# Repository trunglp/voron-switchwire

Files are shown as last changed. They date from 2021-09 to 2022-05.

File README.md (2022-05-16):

# voron-switchwire
Setup and config voron switchwire

https://github.com/VoronDesign/Voron-2/tree/Voron2.4/slicer_profiles/PrusaSlicer

https://www.youtube.com/watch?v=dZEL_ycAOLs

https://www.youtube.com/watch?v=T5TGLleu3MA

https://www.reddit.com/r/klippers/comments/kj2h5r/stepbystep_guide_for_ender_3_v2_klipper_w_bltouch/

https://github.com/VoronDesign/Voron-Switchwire/blob/master/Firmware/skr_mini_e3_v2_config.cfg

update klipper 

https://github.com/Klipper3d/klipper/blob/master/docs/FAQ.md#how-do-i-upgrade-to-the-latest-software

https://github.com/narasak/parrot_3d

https://github.com/Annex-Engineering/Annex-Engineering_User_Mods

https://github.com/VoronDesign/VoronUsers/tree/master/printer_mods/Slidr/PanzerChain2.4/stl

https://github.com/Kruze17/HN_Switchwire

https://github.com/boubounokefalos/Ender_SW

https://github.com/henrikssn/VoronUsers/tree/euler/printer_mods/henrikssn/euler_extruder

https://github.com/kanawati975/Voron_Switchwire

https://githubhelp.com/bcdiaconu/klipper_config

https://github.com/AndrewEllis93/Print-Tuning-Guide

https://github.com/Kruze17/HN_Switchwire/tree/main/Slicer%20configs

https://github.com/hymness1/VoronUsers/tree/148301af584e0df7257529359dd0c115a532dded/printer_mods/hymness1/10x11mm_chain_VSW/STLs

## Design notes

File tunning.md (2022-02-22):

### Cân chỉnh Z OFFSET

```wrap
Send: PROBE_CALIBRATE
Recv: // probe at 107.000,85.000 is z=3.100000
Recv: // Starting manual Z probe. Use TESTZ to adjust position.
Recv: // Finish with ACCEPT or ABORT command.
Recv: // Z position: ?????? --> 8.100 <-- ??????
Recv: ok
[...]
Send: TESTZ z=-8
Recv: // Z position: ?????? --> 0.100 <-- 8.100
Recv: ok
[...]
Recv: // Z position: 0.100 --> 0.200 <-- 0.300
Recv: ok
[...]
Send: TESTZ z=-0.1
Recv: // Z position: 0.000 --> 0.100 <-- 0.200
Recv: ok
[...]
Send: TESTZ z=0.1
Recv: // Z position: 0.100 --> 0.200 <-- 0.300
Recv: ok
[...]
Send: TESTZ z=-0.05
Recv: // Z position: 0.100 --> 0.150 <-- 0.200
Recv: ok
[...]
Send: ACCEPT
Recv: // probe: z_offset: 2.950
Recv: // The SAVE_CONFIG command will update the printer config file
Recv: // with the above and restart the printer.
#### Recv: ok
[...]
Send: SAVE_CONFIG
Recv: ok

```

### Kiểm tra đầu dò xem ổn định không 

```wrap
Send: PROBE_ACCURACY
Recv: // PROBE_ACCURACY at X:107.000 Y:115.000 Z:5.025 (samples=10 retract=2.000 speed=30.0 lift_speed=30.0)
Recv: // probe at 107.000,115.000 is z=2.925000
Recv: // probe at 107.000,115.000 is z=2.937500
Recv: // probe at 107.000,115.000 is z=2.937500
Recv: // probe at 107.000,115.000 is z=2.937500
Recv: // probe at 107.000,115.000 is z=2.937500
Recv: // probe at 107.000,115.000 is z=2.925000
Recv: // probe at 107.000,115.000 is z=2.925000
Recv: // probe at 107.000,115.000 is z=2.925000
Recv: // probe at 107.000,115.000 is z=2.925000
Recv: // probe at 107.000,115.000 is z=2.925000
Recv: // probe accuracy results: maximum 2.937500, minimum 2.925000, range 0.012500, average 2.930000, median 2.925000, standard deviation 0.006124
Recv: ok

```

### Kiểm tra từng trigger 

```wrap 

Send: QUERY_ENDSTOPS
Recv: x:open y:open z:open
Recv: ok
[...]
Send: QUERY_ENDSTOPS
Recv: x:open y:open z:TRIGGERED
Recv: ok

```

### PID Tune Heated Bed
Move nozzle to the center of the bed and approximately 5-10mm above the bed surface, then run:

#### PID_CALIBRATE HEATER=heater_bed TARGET=100

It will perform a PID calibration routine that will last about 10 minutes. Once it is finished, 
type SAVE_CONFIG which will save the parameters into your configuration file.

```wrap

Send: PID_CALIBRATE HEATER=heater_bed TARGET=100
Recv: B:43.5 /100.0 T0:55.7 /0.0
Recv: B:43.5 /100.0 T0:55.6 /0.0
Recv: B:43.5 /100.0 T0:55.4 /0.0
Recv: B:43.5 /100.0 T0:55.3 /0.0
Recv: B:43.5 /100.0 T0:55.1 /0.0
Recv: B:43.5 /100.0 T0:55.0 /0.0
Recv: B:43.5 /100.0 T0:55.0 /0.0
Recv: B:43.5 /100.0 T0:54.9 /0.0

```

### PID Tune HEATER Extruder
ok B:33.4 /0.0 T0:32.7 /0.0
#### PID_CALIBRATE HEATER=extruder TARGET=220

```wrap
PID_CALIBRATE HEATER=extruder TARGET=220
B:33.4 /0.0 T0:32.7 /220.0
B:33.4 /0.0 T0:32.7 /220.0
B:33.4 /0.0 T0:32.7 /220.0
B:33.4 /0.0 T0:32.7 /220.0
// PID parameters: pid_Kp=25.197 pid_Ki=1.098 pid_Kd=144.568
// The SAVE_CONFIG command will update the printer config file
// with these parameters and restart the printer.
```

### Pressure_Advance.md

https://github.com/Klipper3d/klipper/blob/master/docs/Pressure_Advance.md

```wrap
SET_VELOCITY_LIMIT SQUARE_CORNER_VELOCITY=1 ACCEL=500
// max_velocity: 300.000000
// max_accel: 500.000000
// max_accel_to_decel: 3250.000000
// square_corner_velocity: 1.000000
ok
TUNING_TOWER COMMAND=SET_PRESSURE_ADVANCE PARAMETER=ADVANCE START=0 FACTOR=.005
// Starting tuning test (start=0.000000 factor=0.005000)
ok
```

https://github.com/AndrewEllis93/Print-Tuning-Guide#tower-method-simple

1) Download and slice the pressure advance tower with your normal print settings (accelerations included).
The only modifications you should make are these:

```wrap 
    120mm/s external perimeter speed
    1 perimeter
    0% infill
    0 top layers
    0 second "minimum layer time" / "layer time goal"
    High fan speed
```

Pressure Advance => Thay đổi sự phân bố của nhựa , không phải thay đổi số lượng nhựa.

Giá trị thấp hơn dẫn đến ít nhựa hơn ở giữa các dòng và nhiều hơn ở các đầu / góc.

Giá trị cao hơn dẫn đến nhiều nhựa hơn ở giữa các dòng và ít hơn ở các đầu / góc.

Hãy nhớ rằng: Hiếm khi có cái gọi Pressure Advance hoàn hảo 

Việc tăng tốc hoặc giảm tốc hầu như luôn luôn không hoàn hảo. Bạn nên luôn luôn sai lầm về phía các giá trị PA thấp hơn.

Pressure Advance  có thể thay đổi với các nhựa  khác nhau. Nên thay đổi nhựa nhớ tính toán lại

Thông thường, tôi chỉ thấy cần thiết phải điều chỉnh theo từng loại nhựa - ABS, PETG, PLA, TPU,

### input shape 

https://www.youtube.com/watch?v=OoWQUcFimX8

https://www.klipper3d.org/RPi_microcontroller.html

https://www.klipper3d.org/Measuring_Resonances.html













```wrap
Setup 

[mcu rpi]
serial: /tmp/klipper_host_mcu

[adxl345]
cs_pin: rpi:None

[resonance_tester]
accel_chip: adxl345
probe_points:
    100,100,20  # an example
#########################

Send: ACCELEROMETER_QUERY
Recv: // adxl345 values (x, y, z): -9408.500010, -1453.345530, -1300.361790
Recv: ok

TEST_RESONANCES AXIS=X

Send: TEST_RESONANCES AXIS=X
Recv: !! Must home axis first: 107.000 100.000 20.000 [0.000]
Recv: ok
Send: M105
Recv: ok B:30.5 /0.0 T0:58.9 /0.0
Send: M105
Recv: ok B:30.5 /0.0 T0:58.2 /0.0
Send: G91
Recv: ok
Send: G28 Z0
Recv: ok
Send: G90
Recv: ok
Send: M105
Recv: ok B:30.5 /0.0 T0:56.5 /0.0
Send: TEST_RESONANCES AXIS=X
Recv: // max_velocity: 200.000000
Recv: // max_accel: 10000.000000
Recv: // max_accel_to_decel: 10000.000000
Recv: // square_corner_velocity: 4.000000
Recv: // Testing frequency 5 Hz
Recv: // Testing frequency 6 Hz
......

Recv: // Testing frequency 109 Hz
Recv: // Testing frequency 110 Hz
Recv: // Testing frequency 111 Hz
Recv: // Testing frequency 112 Hz
Recv: // Testing frequency 133 Hz
Recv: // max_velocity: 200.000000
Recv: // max_accel: 1000.000000
Recv: // max_accel_to_decel: 500.000000
Recv: // square_corner_velocity: 4.000000
Recv: // xy-axis accelerometer stats: drops=0,overflows=3,time_per_sample=0.000314001,start_range=0.000068,end_range=0.000037
Recv: // Wait for calculations..
Recv: // Resonances data written to /tmp/resonances_x_20211009_032546.csv file
Recv: ok
```    

~/klipper/scripts/calibrate_shaper.py /tmp/resonances_x_*.csv -o /tmp/shaper_calibrate_x.png

~/klipper/scripts/calibrate_shaper.py /tmp/resonances_y_*.csv -o /tmp/shaper_calibrate_y.png

```wrap
pi@octopi:/tmp $ rm resonances_x_20211009_032546.csv
pi@octopi:/tmp $ ~/klipper/scripts/calibrate_shaper.py /tmp/resonances_x_*.csv -o /tmp/shaper_calibrate_x.png
Fitted shaper 'zv' frequency = 34.6 Hz (vibrations = 27.4%, smoothing ~= 0.130)
To avoid too much smoothing with 'zv', suggested max_accel <= 4500 mm/sec^2
Fitted shaper 'mzv' frequency = 26.2 Hz (vibrations = 7.6%, smoothing ~= 0.297)
To avoid too much smoothing with 'mzv', suggested max_accel <= 2000 mm/sec^2
Fitted shaper 'ei' frequency = 32.8 Hz (vibrations = 7.4%, smoothing ~= 0.299)
To avoid too much smoothing with 'ei', suggested max_accel <= 2000 mm/sec^2
Fitted shaper '2hump_ei' frequency = 39.0 Hz (vibrations = 5.4%, smoothing ~= 0.355)
To avoid too much smoothing with '2hump_ei', suggested max_accel <= 1500 mm/sec^2
Fitted shaper '3hump_ei' frequency = 48.0 Hz (vibrations = 5.3%, smoothing ~= 0.356)
To avoid too much smoothing with '3hump_ei', suggested max_accel <= 1500 mm/sec^2
Recommended shaper is mzv @ 26.2 Hz
```   





```wrap
[input_shaper]
shaper_freq_x: 27
shaper_freq_y: 36
shaper_type: mzv
```

### Selecting max_accel

https://www.klipper3d.org/Resonance_Compensation.html

https://www.klipper3d.org/prints/ringing_tower.stl

```wrap
SET_PRESSURE_ADVANCE ADVANCE=0
// pressure_advance: 0.000000
// pressure_advance_smooth_time: 0.040000
ok
TUNING_TOWER COMMAND=SET_VELOCITY_LIMIT PARAMETER=ACCEL START=1250 FACTOR=100 BAND=5
// Ending tuning test mode
// Starting tuning test (start=1250.000000 factor=100.000000)
ok
TUNING_TOWER COMMAND=SET_VELOCITY_LIMIT PARAMETER=ACCEL START=1250 FACTOR=100 BAND=5
// Ending tuning test mode
// Starting tuning test (start=1250.000000 factor=100.000000)
```

# Verify stepper_buzz
```wrap
STEPPER_BUZZ STEPPER=stepper_z
STEPPER_BUZZ STEPPER=stepper_z1
STEPPER_BUZZ STEPPER=stepper_z2
```

https://www.reddit.com/r/klippers/comments/gxnxij/trying_different_retract_settings_with_tuning/

# Tuning retract
```wrap
[firmware_retraction]
retract_length: 0.8
#   The length of filament (in mm) to retract when G10 is activated, and to
#   unretract when G11 is activated (but see unretract_extra_length below).
#   The default is 0 mm.
retract_speed: 40
#   The length (in mm) of *additional* filament to add when unretracting.
unretract_extra_length: 0
#   The speed of retraction, in mm/s. The default is 20 mm/s.
unretract_speed: 40
######################
[gcode_macro SET_RETRACTIONLENGTH]
gcode:
  SET_RETRACTION RETRACT_LENGTH={params.LENGTH|float}
  GET_RETRACTION
```

```wrap
TUNING_TOWER COMMAND=SET_RETRACTIONLENGTH PARAMETER=LENGTH START=0.5 FACTOR=.007
```

```wrap
setup slicer:
set 0 retraction length (PrusaSlicer/SuperSlicer: Printer Settings -> Extruder 1 -> Retraction -> Length)
disable wipe (PrusaSlicer/SuperSlicer: Printer Settings -> Extruder 1 -> Retraction -> Wipe while retracting)
enable use firmware retractions (PrusaSlicer/SuperSlicer: Printer Settings -> General -> Advanced -> Use firmware retractions)
```

### Extrusion multiplier và Pressure Advance Có quan hệ với nhau, nên chỉnh 1 trong 2 giá trị không đúng dẫn đến in không đẹp 

Approximate Values
|Hotend  |	Flow Rate (mm3/sec) |
| --- | --- |
|E3D V6  |	11
|E3D Revo |	15
|Dragon SF|	15
|Dragon HF |	24
|Mosquito |	20
|Mosquito Magnum |	30

## cHow Volumetric Flow Rate Relates to Print Speed

Working out how quickly you can print at a given volumetric flow rate is quite simple:

   ### speed = volumetric flow / layer height / line width
    
  ####  167  = 15 / 0.2 / 0.45 
    
  ####  222  = 20 / 0.2 / 0.45 
    
Or, inversely,

 ### volumetric flow = speed * line width * layer height

For example, if your hotend is capable of 24mm3/sec, and you are printing with 0.4mm line width, at 0.2mm layer height:

    24 / 0.4 / 0.2 = Maximum print speed of 300mm/sec

```wrap
# Home, get position, throw around toolhead, home again.
# If MCU stepper positions (first line in GET_POSITION) are greater than a full step different (your number of microsteps), then skipping occured.
# We only measure to a full step to accomodate for endstop variance.
# Example: TEST_SPEED SPEED=300 ACCEL=5000 ITERATIONS=10
[gcode_macro TEST_SPEED]
gcode:
	# Speed
	{% set speed  = params.SPEED|default(printer.configfile.settings.printer.max_velocity)|int %}
	# Iterations
	{% set iterations = params.ITERATIONS|default(5)|int %}
	# Acceleration
	{% set accel  = params.ACCEL|default(printer.configfile.settings.printer.max_accel)|int %}
	# Bounding box (in case the machine min/maxes are not perfect)
	{% set bound = params.BOUND|default(20)|int %}
	
	# Set speed test bounds (machine minimum/maximum positions, inset by the bounding box)
	{% set x_min = printer.toolhead.axis_minimum.x + bound %}
	{% set x_max = printer.toolhead.axis_maximum.x - bound %}
	{% set y_min = printer.toolhead.axis_minimum.y + bound %}
	{% set y_max = printer.toolhead.axis_maximum.y - bound %}

	# Save current gcode state (absolute/relative, etc)
	SAVE_GCODE_STATE NAME=TEST_SPEED
	
	{ action_respond_info("TEST_SPEED: starting %d iterations at speed %d, accel %d" % (iterations, speed, accel)) }

	# Absolute positioning
	G90
	
	# Set new limits
	SET_VELOCITY_LIMIT VELOCITY={speed} ACCEL={accel} ACCEL_TO_DECEL={accel / 2}

	# Home and get position for comparison later:
		G28
		# QGL if not already QGLd (only if QGL section exists in config)
		{% if printer.configfile.settings.quad_gantry_level %}
			{% if printer.quad_gantry_level.applied == False %}
				QUAD_GANTRY_LEVEL
				G28 Z
			{% endif %}
		{% endif %}	
		G0 X{printer.toolhead.axis_maximum.x} Y{printer.toolhead.axis_maximum.y} F{30 * 60}
		G4 P1000 
		GET_POSITION

	# Go to starting position
	G0 X{x_min} Y{y_min} Z{bound + 10} F{speed * 60}

	{% for i in range(iterations) %}
		# Diagonals
		G0 X{x_min} Y{y_min} F{speed * 60}
		G0 X{x_max} Y{y_max} F{speed * 60}
		G0 X{x_min} Y{y_min} F{speed * 60}
		G0 X{x_max} Y{y_min} F{speed * 60}
		G0 X{x_min} Y{y_max} F{speed * 60}
		G0 X{x_max} Y{y_min} F{speed * 60}
		
		# Box
		G0 X{x_min} Y{y_min} F{speed * 60}
		G0 X{x_min} Y{y_max} F{speed * 60}
		G0 X{x_max} Y{y_max} F{speed * 60}
		G0 X{x_max} Y{y_min} F{speed * 60}
	{% endfor %}

	# Restore max speed/accel/accel_to_decel to their configured values
	SET_VELOCITY_LIMIT VELOCITY={printer.configfile.settings.printer.max_velocity} ACCEL={printer.configfile.settings.printer.max_accel} ACCEL_TO_DECEL={printer.configfile.settings.printer.max_accel_to_decel} 

	# Re-home XY and get position again for comparison:
		G28 X Y
		# Go to XY home positions (in case your homing override leaves it elsewhere)
		G0 X{printer.toolhead.axis_maximum.x} Y{printer.toolhead.axis_maximum.y} F{30 * 60}
		G4 P1000 
		GET_POSITION

	# Restore previous gcode state (absolute/relative, etc)
	RESTORE_GCODE_STATE NAME=TEST_SPEED
    
```

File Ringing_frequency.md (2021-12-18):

Setup slicer 









Increase max_accel and max_accel_to_decel parameters in your printer.cfg to 7000. Note that this is only needed for tuning, and more proper value will be selected in the corresponding section.
If square_corner_velocity parameter was changed, revert it back to 5.0. It is not advised to increase it when using the input shaper because it can cause more smoothing in parts - it is better to use higher acceleration value instead.
Restart the firmware: RESTART.
Disable Pressure Advance: SET_PRESSURE_ADVANCE ADVANCE=0.
If you have already added [input_shaper] section to the printer.cfg, execute SET_INPUT_SHAPER SHAPER_FREQ_X=0 SHAPER_FREQ_Y=0 command. If you get "Unknown command" error, you can safely ignore it at this point and continue with the measurements.
Execute the command TUNING_TOWER COMMAND=SET_VELOCITY_LIMIT PARAMETER=ACCEL START=1250 FACTOR=100 BAND=5. Basically, we try to make ringing more pronounced by setting different large values for acceleration. This command will increase the acceleration every 5 mm starting from 1500 mm/sec^2: 1500 mm/sec^2, 2000 mm/sec^2, 2500 mm/sec^2 and so forth up until 7000 mm/sec^2 at the last band.
Print the test model sliced with the suggested parameters.
You can stop the print earlier if the ringing is clearly visible and you see that acceleration gets too high for your printer (e.g. printer shakes too much or starts skipping steps).

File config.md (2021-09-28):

# voron-switchwire

### Setup and config voron switchwire on SKR Mini E3 V1.2

MainsailOS or FluiddPi or Octoprint



### Step 1: 

git clone https://github.com/Klipper3d/klipper

./klipper/scripts/install-octopi.sh

### Step 2:

cd ~/klipper/

make menuconfig



Chú ý: 

SKR mini E3 V1.2 => pin !PC13
SKR mini E3 V2.0 => pin !PC14

### Step 3: build firmware

```wrap

pi@octopi:~/klipper $ make clean
pi@octopi:~/klipper $ make
  Creating symbolic link out/board
  Building out/autoconf.h
  Compiling out/src/sched.o
  Compiling out/src/command.o
  Compiling out/src/basecmd.o
  Compiling out/src/debugcmds.o
  Compiling out/src/initial_pins.o
  Compiling out/src/gpiocmds.o
  Compiling out/src/stepper.o
  Compiling out/src/endstop.o
  Compiling out/src/trsync.o
  Compiling out/src/adccmds.o
  Compiling out/src/spicmds.o
  Compiling out/src/thermocouple.o
  Compiling out/src/i2ccmds.o
  Compiling out/src/pwmcmds.o
  Compiling out/src/spi_software.o
  Compiling out/src/sensor_adxl345.o
  Compiling out/src/lcd_st7920.o
  Compiling out/src/lcd_hd44780.o
  Compiling out/src/buttons.o
  Compiling out/src/tmcuart.o
  Compiling out/src/neopixel.o
  Compiling out/src/pulse_counter.o
  Compiling out/src/stm32/watchdog.o
  Compiling out/src/stm32/gpio.o
  Compiling out/src/generic/crc16_ccitt.o
  Compiling out/src/generic/armcm_boot.o
  Compiling out/src/generic/armcm_irq.o
  Compiling out/src/generic/armcm_reset.o
  Compiling out/src/../lib/stm32f1/system_stm32f1xx.o
  Compiling out/src/stm32/stm32f1.o
  Compiling out/src/generic/armcm_timer.o
  Compiling out/src/stm32/adc.o
  Compiling out/src/stm32/i2c.o
  Compiling out/src/stm32/spi.o
  Compiling out/src/stm32/usbfs.o
  Compiling out/src/stm32/chipid.o
  Compiling out/src/generic/usb_cdc.o
  Compiling out/src/stm32/hard_pwm.o
  Building out/compile_time_request.o
Version: v0.9.1-659-g69d9497d
  Preprocessing out/src/generic/armcm_link.ld
  Linking out/klipper.elf
  Creating hex file out/klipper.bin
pi@octopi:~/klipper $

```

### Check my config

```wrap

pi@octopi:~/klipper $ cat .config
CONFIG_LOW_LEVEL_OPTIONS=y
# CONFIG_MACH_AVR is not set
# CONFIG_MACH_ATSAM is not set
# CONFIG_MACH_ATSAMD is not set
# CONFIG_MACH_LPC176X is not set
CONFIG_MACH_STM32=y
# CONFIG_MACH_RP2040 is not set
# CONFIG_MACH_PRU is not set
# CONFIG_MACH_LINUX is not set
# CONFIG_MACH_SIMU is not set
CONFIG_STEP_DELAY=2
CONFIG_BOARD_DIRECTORY="stm32"
CONFIG_MCU="stm32f103xe"
CONFIG_CLOCK_FREQ=72000000
CONFIG_USBSERIAL=y
CONFIG_FLASH_START=0x8007000
CONFIG_FLASH_SIZE=0x10000
CONFIG_RAM_START=0x20000000
CONFIG_RAM_SIZE=0x5000
CONFIG_STACK_SIZE=512
CONFIG_STM32_SELECT=y
CONFIG_MACH_STM32F103=y
# CONFIG_MACH_STM32F207 is not set
# CONFIG_MACH_STM32F401 is not set
# CONFIG_MACH_STM32F405 is not set
# CONFIG_MACH_STM32F407 is not set
# CONFIG_MACH_STM32F429 is not set
# CONFIG_MACH_STM32F446 is not set
# CONFIG_MACH_STM32F031 is not set
# CONFIG_MACH_STM32F042 is not set
# CONFIG_MACH_STM32F070 is not set
# CONFIG_MACH_STM32F072 is not set
CONFIG_MACH_STM32F1=y
CONFIG_HAVE_STM32_USBFS=y
CONFIG_HAVE_STM32_CANBUS=y
# CONFIG_STM32_FLASH_START_2000 is not set
# CONFIG_STM32_FLASH_START_5000 is not set
CONFIG_STM32_FLASH_START_7000=y
# CONFIG_STM32_FLASH_START_8800 is not set
# CONFIG_STM32_FLASH_START_10000 is not set
# CONFIG_STM32_FLASH_START_800 is not set
# CONFIG_STM32_FLASH_START_4000 is not set
# CONFIG_STM32_FLASH_START_0000 is not set
CONFIG_STM32_CLOCK_REF_8M=y
# CONFIG_STM32_CLOCK_REF_12M is not set
# CONFIG_STM32_CLOCK_REF_16M is not set
# CONFIG_STM32_CLOCK_REF_25M is not set
# CONFIG_STM32_CLOCK_REF_INTERNAL is not set
CONFIG_CLOCK_REF_FREQ=8000000
CONFIG_STM32F0_TRIM=16
CONFIG_STM32_USB_PA11_PA12=y
# CONFIG_STM32_SERIAL_USART1 is not set
# CONFIG_STM32_SERIAL_USART1_ALT_PB7_PB6 is not set
# CONFIG_STM32_SERIAL_USART2 is not set
# CONFIG_STM32_SERIAL_USART2_ALT_PD6_PD5 is not set
# CONFIG_STM32_SERIAL_USART3 is not set
# CONFIG_STM32_SERIAL_USART3_ALT_PD9_PD8 is not set
# CONFIG_STM32_CANBUS_PA11_PA12 is not set
# CONFIG_STM32_CANBUS_PB8_PB9 is not set
CONFIG_CANBUS_FREQUENCY=500000
CONFIG_USB_VENDOR_ID=0x1d50
CONFIG_USB_DEVICE_ID=0x614e
CONFIG_USB_SERIAL_NUMBER_CHIPID=y
CONFIG_USB_SERIAL_NUMBER="12345"

#
# USB ids
#
# end of USB ids

# CONFIG_CUSTOM_STEP_DELAY is not set
CONFIG_INITIAL_PINS="!PC13"
CONFIG_HAVE_GPIO=y
CONFIG_HAVE_GPIO_ADC=y
CONFIG_HAVE_GPIO_SPI=y
CONFIG_HAVE_GPIO_I2C=y
CONFIG_HAVE_GPIO_HARD_PWM=y
CONFIG_HAVE_GPIO_BITBANGING=y
CONFIG_HAVE_STRICT_TIMING=y
CONFIG_HAVE_CHIPID=y
CONFIG_INLINE_STEPPER_HACK=y

```

### Step 4: Copy klipper.bin  to sd card and rename to FIRMWARE.BIN => flash firmware board SKR mini E3 V1.2

```wrap

pi@octopi:~/klipper $ pwd
/home/pi/klipper
pi@octopi:~/klipper $ ls out/
autoconf.h     board-link              compile_time_request.o    klipper.dict  src
board          compile_time_request.c  compile_time_request.txt  klipper.elf
board-generic  compile_time_request.d  klipper.bin               lib
pi@octopi:~/klipper $

```

### Step 5:



### Step 6:





### Step 7:



### Tham Khảo





https://www.youtube.com/watch?v=c7cVv9qbSMw

################################

https://www.youtube.com/watch?v=T5TGLleu3MA

https://docs.vorondesign.com/build/software/miniE3_v12_klipper.html

https://www.reddit.com/r/ender3/comments/dtl8re/skr_mini_e3_12_klipper_configguide_including/

https://github.com/Klipper3d/klipper/blob/master/config/generic-bigtreetech-skr-mini-e3-v1.2.cfg

https://github.com/Klipper3d/klipper/tree/master/config

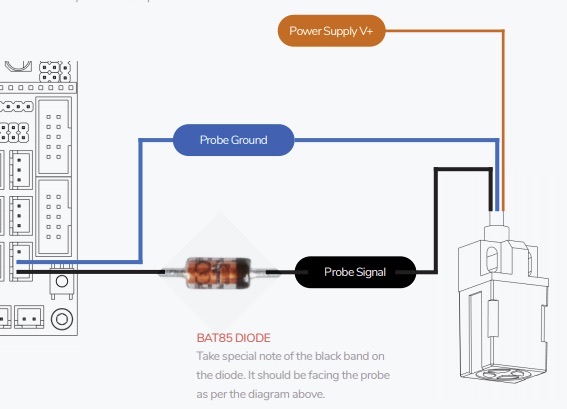
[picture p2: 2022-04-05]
6FBBFF84-A0F4-4B92-9275-398039277366.jpeg

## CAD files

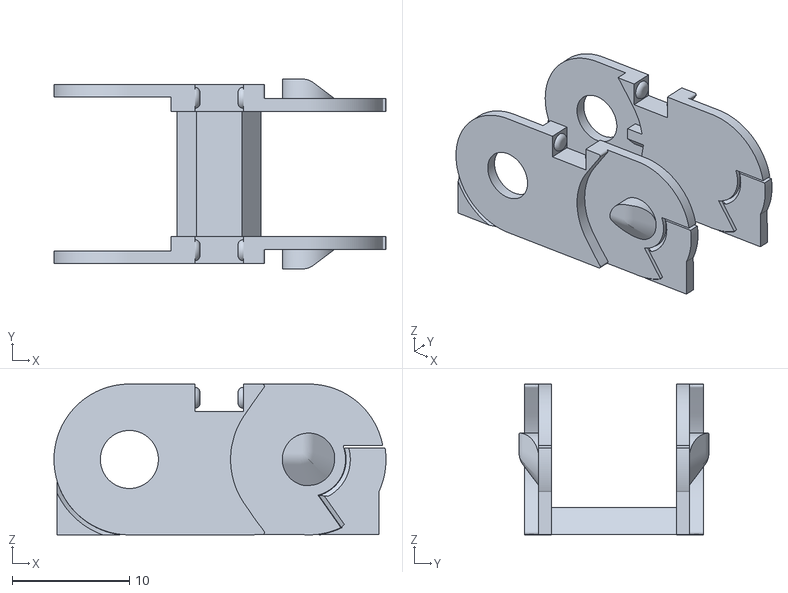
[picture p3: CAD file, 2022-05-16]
STL/chainlink_fix.stl
28.3 x 16.2 x 12.9

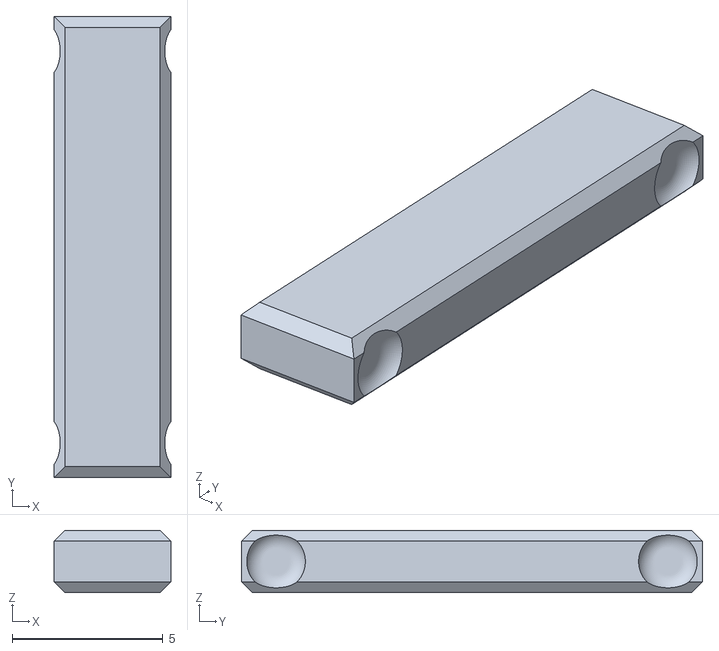
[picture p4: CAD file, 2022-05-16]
STL/clip_fix.stl
3.87 x 15.3 x 2.07

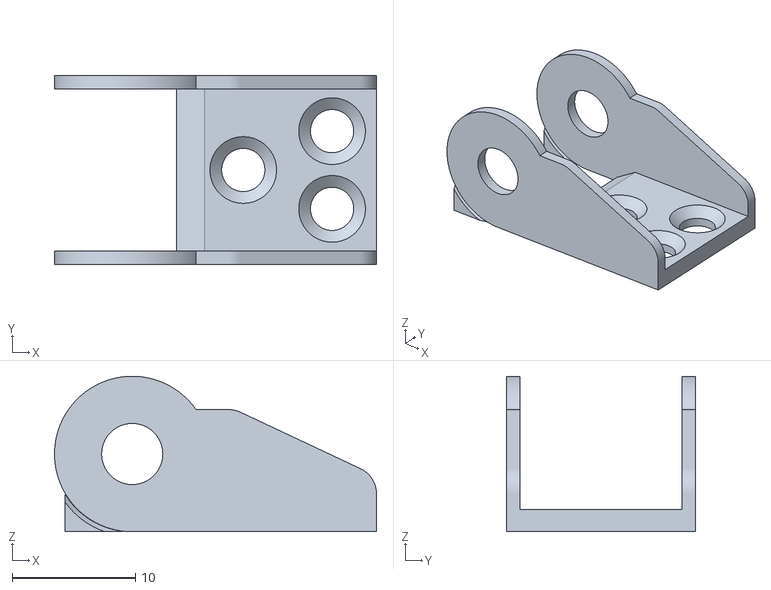
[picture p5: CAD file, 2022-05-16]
STL/unfixed_end_PT90_fix.stl
26.1 x 15.3 x 12.6

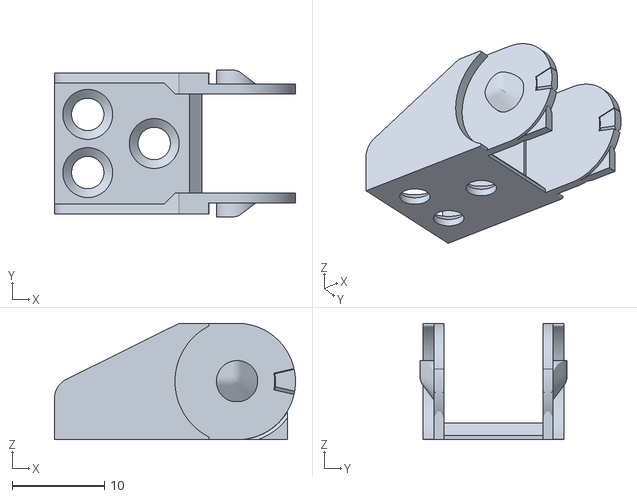
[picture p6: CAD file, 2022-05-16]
STL/fixed_end_90PT_fix.stl
26.1 x 15.9 x 12.6

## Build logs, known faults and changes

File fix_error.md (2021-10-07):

Nếu gặp lỗi "min_temp or max_temp" => nguyên nhân dây Sensor bị đứt hoặc không gắn dây sensor

```wrap 

Recv: // MCU 'mcu' shutdown: ADC out of range
Recv: // This generally occurs when a heater temperature exceeds
Recv: // its configured min_temp or max_temp.
Recv: // Once the underlying issue is corrected, use the
Recv: // "FIRMWARE_RESTART" command to reset the firmware, reload the
Recv: // config, and restart the host software.
Recv: // Printer is shutdown
Recv: // Klipper state: Not ready
Recv: !! MCU 'mcu' shutdown: ADC out of range

```

Không thể move các axis X Y Z khi chưa homing

If the motors are disabled (via an M84 or M18 command) then the motors will need to be homed again prior to movement.

#### Lỗi Move exceeds maximum extrusion (0.752mm^2 vs 0.640mm^2)
Your printer's firmware reported an error. Due to that the ongoing print job will be cancelled. Reported error: Move exceeds maximum extrusion (0.752mm^2 vs 0.640mm^2)
=> put M82 at the end of START_PRINT to revert the effect of M83
M83 or G92 E0 causing "move exceeds max extrusion"

#### Lỗi  pid_calibrate interrupted

```wrap
Recv: // Klipper state: Shutdown
Recv: !! pid_calibrate interrupted

Fix: 

[verify_heater bed]  
heating_gain: 2 
check_gain_time:35  
hysteresis: 10  
max_error: 130 
```

#### LỖI KHÔNG KẾT NỐI VỚI MCU

Nguyên nhân lỗi này là do Cáp kết nối , file config MCU, Thẻ nhớ SD card cần format lại đúng chuẩn

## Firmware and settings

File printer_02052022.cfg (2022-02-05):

##klipper SKR Mini E3 V1.2 edit by lptrung
############################# ##########
##
#[mcu rpi]
#serial: /tmp/klipper_host_mcu

#[adxl345]
#cs_pin: rpi:None

#[resonance_tester]
##accel_chip: adxl345
#probe_points:
#    107,100,20  # an example    
######################################


[printer]
kinematics: corexz
##############################
#max_velocity: 200
#max_accel: 1000
#max_z_velocity: 50
#max_z_accel: 1000
#square_corner_velocity: 4.0
##################################

#kinematics: corexz
#max_velocity: 200
#max_accel: 1000
#max_z_velocity: 50
#max_z_accel: 1000
#square_corner_velocity: 4.0

max_velocity: 250
max_accel: 2200
max_accel_to_decel: 1500
max_z_velocity: 24
max_z_accel: 400
square_corner_velocity: 4.0



[force_move]
enable_force_move: true

### Test XYZ
#max_velocity: 500
#max_accel: 7000
#max_accel_to_decel: 7000
#max_z_velocity: 100
#max_z_accel: 1000
#square_corner_velocity: 5

#max_velocity: 300
#max_accel: 3250
#max_accel_to_decel: 3250
#max_z_velocity: 100
#max_z_accel: 1000
#square_corner_velocity: 5.0


[input_shaper]
#shaper_type: mzv
#shaper_freq_x: 26   ## 100 x 6 / 16 =37.5
#shaper_freq_y: 33.8  ### 600 /14 = 42.8

shaper_type_x: ei
#shaper_freq_x: 0
shaper_freq_x: 38.0 ## accel <=1900
shaper_type_y: mzv   ## accel <=3800
shaper_freq_y: 33.8
#shaper_freq_y: 0
#shaper_type_y: ei   ## accel <=3800
#shaper_freq_y: 42.8

[probe]
##pin: !PA1
pin: ^!PC14

#khoang cach tu mui in toi dau do ( Probe) 
x_offset: 0.0
y_offset: 25.0
##For moquito 
#z_offset = 1.930
## MK8
#z_offset: 1.9
speed: 50
##speed: 100 ##tesst
#samples: 3
#samples_result: median
sample_retract_dist: 5
#lift_speed: 50

#samples: 3
#samples_result: average

#sample_retract_dist: 1
#lift_speed: 50

[stepper_x]
step_pin: PB13
dir_pin: PB12
enable_pin: !PB14
microsteps: 16
rotation_distance: 39.7
endstop_pin: ^PC0
position_endstop: 215
position_max: 215
homing_speed: 50

[tmc2209 stepper_x]
uart_pin: PB15
run_current: 0.45
hold_current: 0.3
stealthchop_threshold: 250


[stepper_y]
step_pin: PB10
dir_pin: !PB2
enable_pin: !PB11
microsteps: 16
rotation_distance: 39.8
endstop_pin: ^PC1
position_endstop: 210
position_max: 210
homing_speed: 50

[tmc2209 stepper_y]
uart_pin: PC6
run_current: 0.5
hold_current: 0.3
stealthchop_threshold: 250

[stepper_z]
step_pin: PB0
dir_pin: PC5
enable_pin: !PB1
microsteps: 16
rotation_distance: 39.7
endstop_pin: probe:z_virtual_endstop
position_max: 220
position_min: -2
homing_speed: 40

[tmc2209 stepper_z]
uart_pin: PC10
run_current: 0.45
hold_current: 0.3
stealthchop_threshold: 250


[extruder]
step_pin: PB3
dir_pin: PB4
enable_pin: !PD2
microsteps: 16
rotation_distance: 4.44
nozzle_diameter: 0.400
filament_diameter: 1.750
heater_pin: PC8
min_temp: 0
max_temp: 260
min_extrude_temp: 50
sensor_pin: PA0
max_extrude_only_distance: 100.0
##lptrung edit
#pressure_advance: 0.044  ###gia tri 8.4
##pressure_advance:0.045 ### KQ= 9*0.005 = 0.045
pressure_advance:0.04  ### KQ= 30*0.005 = 0.015
pressure_advance_smooth_time: 0.040
## nhua can nong chay, gia tri la 0.03 se khong bi dut doan
###m ender 3 pro  ####  MK8 OK
#sensor_type: EPCOS 100K B57560G104F   
#control = pid
##pid_Kp=33.750
#pid_Ki=2.009
#pid_Kd=141.749

###m Mosquito  #### 
#sensor_type: EPCOS 100K B57560G104F   
#control = pid
#pid_Kp=33.796
#pid_Ki=1.976
#pid_Kd=144.479


###m Mosquito ok  #### 
sensor_type: NTC 100K MGB18-104F39050L32
control: pid
pid_Kp=32.815
pid_Ki=1.971
pid_Kd=136.591


#[thermistor mosquito_thermistor]
#temperature1 = 20
#resistance1 = 613400
#temperature2 = 190
#resistance2 = 4509
#temperature3 = 260
#resistance3 = 1359

[tmc2209 extruder]
uart_pin: PC11
run_current: 0.25
hold_current: 0.2
stealthchop_threshold: 250

### Z homing
[homing_override]
axes: z
set_position_z: 0
gcode:
    G90
    BED_MESH_CLEAR
    STATUS_HOMING
    G0 Z5 F500
    G28 X0 Y0
    G0 X107 Y85 F9000
    ##G0 X5 Y5 F2000
    G28 Z0 F200
    G0 Z5 F500

[bed_mesh]
speed: 100
#speed: 130  ## tesst
horizontal_move_z: 5
mesh_min: 25,25
mesh_max: 190,195
probe_count: 5,5
fade_end: 10
split_delta_z: .01
move_check_distance: 3
algorithm: lagrange
mesh_pps : 2,2
relative_reference_index: 12

#mesh_pps : 5,5
#bicubic_tension: 0.8
#split_delta_z: 0.025
#fade_end: 10  ### gia tri 2 ban khong phang
#split_delta_z: 0.01
#move_check_distance: 3
#mesh_pps : 2,2
#algorithm: lagrange  ##lagrange
#relative_reference_index: 12



[heater_bed]
heater_pin: PC9
sensor_type: EPCOS 100K B57560G104F
#lptrung sensor_type: ATC Semitec 104GT-2
sensor_pin: PC3
control = pid
pid_kp = 70.844
pid_ki = 1.414
pid_kd = 887.318
min_temp: 0
max_temp: 110
###// PID parameters: pid_Kp=70.844 pid_Ki=1.414 pid_Kd=887.318
[fan]
pin: PA8

# thermally controlled hotend fan
#lptrung  [heater_fan my_nozzle_fan]
#lptrung  pin: PC7
#lptrung  max_power: 1.0
kick_start_time: 0.100
#lptrung  heater: extruder
#lptrung  heater_temp: 50.0
#lptrung  fan_speed: 1.0




[mcu]
serial: /dev/serial/by-id/usb-Klipper_stm32f103xe_34FFD7055055323921710143-if00


[static_digital_output usb_pullup_enable]
pins: !PC13

[board_pins]
aliases:
    # EXP1 header
    EXP1_1=PB5, EXP1_3=PA9,   EXP1_5=PA10, EXP1_7=PB8, EXP1_9=<GND>,
    EXP1_2=PB6, EXP1_4=<RST>, EXP1_6=PB9,  EXP1_8=PB7, EXP1_10=<5V>

# See the sample-lcd.cfg file for definitions of common LCD displays.

######################################################################
# 128x64 Full Graphic Creality CR10 / ENDER 3 stockdisplay
######################################################################

# This section is used for a Creality "12864" display with a single
# ribbon cable between the display's EXP3 plug and the
# micro-controller board's EXP1 connector.

[display]
lcd_type: st7920
cs_pin: EXP1_7
sclk_pin: EXP1_6
sid_pin: EXP1_8
encoder_pins: ^EXP1_5, ^EXP1_3
click_pin: ^!EXP1_2

[output_pin beeper]
pin: EXP1_1

[virtual_sdcard]
path: /home/pi/sdcard

################
[gcode_macro G29]
gcode:
    BED_MESH_CLEAR
    BED_MESH_CALIBRATE
    BED_MESH_PROFILE SAVE=default
    BED_MESH_PROFILE LOAD=default
    
###############LED################
[neopixel sb_leds]
pin: PA1
chain_count: 3
color_order: GRBW
initial_RED: 0.0
initial_GREEN: 0.0
initial_BLUE: 0.0
initial_WHITE: 0.0

[gcode_macro status_off]
gcode:
    set_logo_leds_off transmit=0
    set_nozzle_leds_off
	
# #   Sets the initial LED color of the Neopixel. Each value should be
# #   between 0.0 and 1.0. The WHITE option is only available on RGBW
# #   LEDs. The default for each color is 0.#
#
# Most configuration for the macros can be done by modifying the variables in the _sb_vars macro
# at the start of this file. 
#
# MACROS
#
# The following status macros are available:
#    STATUS_READY
#    STATUS_OFF
#    STATUS_BUSY
#    STATUS_HEATING
#    STATUS_LEVELING
#    STATUS_HOMING
#    STATUS_CLEANING
#    STATUS_MESHING
#    STATUS_CALIBRATING_Z
# With additional macros for direct control:
#    SET_NOZZLE_LEDS_ON
#    SET_LOGO_LEDS_OFF
#    SET_NOZZLE_LEDS_OFF
#
# Contributed by Voron discord users wile.e, Tetsunosuke, and etherwalker

[gcode_macro _sb_vars]
# User settings for the StealthBurner status leds. You can change the status colors and led
# configurations for the logo and nozzle here.
variable_colors: {
        'logo': { # Colors for logo states
            'busy': {'r': 0.4, 'g': 0.0, 'b': 0.0, 'w': 0.0},
            'cleaning': {'r': 0.0, 'g': 0.02, 'b': 0.5, 'w': 0.0},
            'calibrating_z': {'r': 0.8, 'g': 0., 'b': 0.35, 'w': 0.0},
            'heating': {'r': 0.3, 'g': 0.18, 'b': 0.0, 'w': 0.0},
            'homing': {'r': 0.0, 'g': 0.6, 'b': 0.2, 'w': 0.0},
            'leveling': {'r': 0.5, 'g': 0.1, 'b': 0.4, 'w': 0.0},
            'meshing': {'r': 0.2, 'g': 1.0, 'b': 0.0, 'w': 0.0},
            'off': {'r': 0.0, 'g': 0.0, 'b': 0.0, 'w': 0.0},
            'printing': {'r': 1.0, 'g': 0.0, 'b': 0.0, 'w': 0.0},
            'standby': {'r': 0.01, 'g': 0.01, 'b': 0.01, 'w': 0.1},
        },
        'nozzle': { # Colors for nozzle states
            'heating': {'r': 0.8, 'g': 0.35, 'b': 0.0, 'w':0.0},
            'off': {'r': 0.0, 'g': 0.0, 'b': 0.0, 'w': 0.0},
            'on': {'r': 0.8, 'g': 0.8, 'b': 0.8, 'w':1.0},
            'standby': {'r': 0.6, 'g': 0.0, 'b': 0.0, 'w':0.0},
        },
        'thermal': {
            'hot': {'r': 1.0, 'g': 0.0, 'b': 0.0, 'w': 0.0},
            'cold': {'r': 0.3, 'g': 0.0, 'b': 0.3, 'w': 0.0}
        }
    }
variable_logo_led_name:         "sb_leds" 
# The name of the addressable LED chain that contains the logo LED(s)
variable_logo_idx:              "1" 
# A comma-separated list of indexes LEDs in the logo
variable_nozzle_led_name:       "sb_leds"
# The name of the addressable LED chain that contains the nozzle LED(s). This will
# typically be the same LED chain as the logo.
variable_nozzle_idx:            "2,3"
# A comma-separated list of indexes of LEDs in the nozzle
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
